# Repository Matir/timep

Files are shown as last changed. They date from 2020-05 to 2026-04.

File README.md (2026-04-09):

# Test Interface for Multiple Embedded Protocols

This is an Open Source Hardware board based around the FTDI FT2232H chip to
provide breakouts, buffering, and level conversion for a number of common
embedded hardware interfaces.  At present, this includes:

* SPI
* I2C
* JTAG
* SWD
* UART

It's intended to be easy to use and work with open source software, including
tools like OpenOCD and Flashrom.

## Archived

**This will not be maintained in any way. This eventually served as a prototype
and inspiration for [Tigard](https://github.com/tigard-tools/tigard), which was
productionized by [@securelyfitz](https://github.com/securelyfitz).**

## Usage

### Hardware Hookup

The hardware has dedicated headers for a variety of electrical interfaces.
Connect the desired interface to you target.  The pinout for SPI, I2C and UART
are printed on the board, SWD follows the ARM SWD standard, and JTAG is the ARM
20 pin JTAG interface.  (Electrically, however, it should work with most any
processor supporting JTAG.)

You may only use one of the SPI, I2C, SWD, and JTAG interfaces at any given
time.  The UART is handled by dedicated pins in the FT2232H, so can be used
simultaneously with one of the other interfaces.

There are 3 switches on the board.  The mode switch selects how the reference
power (for the interface) and the target are connected:

* **Isolated**: The interface is powered by the on-board voltage regulators, and the
  target must be powered by its own power supplies.  The power rails are not
  connected to one another.  You will almost always want to use this mode.
* **Bridged**: The interface is powered by the on-board voltage regulators which
  will also supply power to the target.  **The target must not be separately
  powered.**  This mode is useful for e.g., programming SPI/I2C flash out of
  circuit, or powering very small circuits -- maximum stable load is around 200mA.
* **Target**: The interface is partially powered from the target.
  (Specifically, the reference voltage for the level shifters.)  In theory, this
  can be used for cases where the target voltage is not 5v, 3.3v, or 1.8v.  The
  target voltage must still remain under 5V!

Note that the *ground* of your computer is connected to the *ground* of your
target when you connect with this.  In almost all cases, this is not a problem,
but if both are powered via the wall ("mains"), there is a risk of noise due to
ground loops, etc.

The voltage switch allows you to select the I/O voltage used in `Isolated` or
`Bridged` mode.  It does nothing (well, except change an LED) in `Target` mode.
5V is supplied directly from the USB input, and there are onboard regulators
for 3.3v and 1.8v.

The remaining switch selects between JTAG/SPI and I2C/SWD.  I2C and SWD use a
bidirectional data line, so require special handling.

### Software

I've tested the board with `OpenOCD` for JTAG/SWD use and `flashrom` for SPI/I2C
flash.  I'm planning to make a demo target board with a handful of interfaces on
it and provide that here in the future.

With `OpenOCD`, use the configuration file in `configs`.  You will also need a
target configuration.  Time permitting, I will post a tutorial on the use of
TIMEP and OpenOCD to debug targets.

With `flashrom`:

```
flashrom -p ft2232_spi:type=2232H,port=B,divisor=4
```

Use of `port=B` is critical, port `A` is wired to the UART, so will not work as
you intend.  :)

### Protections

Some efforts have been made to protect against mistakes that will destroy your
hardware, but there is still some risk in using this if connected improperly.

Included protection in current revision:

* Current limiting resistors on I/O lines.
* 5v+ tolerant I/O.
* Warnings in the README.  :)

Shorting power to ground may damage the target, the TIMEP interface, or the USB
port on your computer (if running in 5V mode).  This is unlikely, but be careful
with your connections.

Using the wrong voltage may damage components not rated for that voltage.  Any
voltage up to 5v is tolerated on the interface board I/O pins, but beyond that
may result in damage.

Additional protection that could be considered:

* Polyfuses on power/ground rails to computer.
* Clamping diodes on USB lines.
* Clamping diodes on I/O lines.

These have not been added because I have been trying to keep BOM cost down to
get these in the hands of as many hardware hackers as possible.

## License

Copyright 2020 Google, LLC

Maintainer: David Tomaschik <david@systemoverlord.com>

Please see [CONTRIBUTORS.md](CONTRIBUTORS.md) for credit to all contributors.

Licensed under the Apache License, Version 2.0 (the "License");
you may not use this file except in compliance with the License.
You may obtain a copy of the License at

    https://www.apache.org/licenses/LICENSE-2.0

Unless required by applicable law or agreed to in writing, software
distributed under the License is distributed on an "AS IS" BASIS,
WITHOUT WARRANTIES OR CONDITIONS OF ANY KIND, either express or implied.
See the License for the specific language governing permissions and
limitations under the License.

This is not an officially supported Google product.

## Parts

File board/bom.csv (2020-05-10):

Reference | Value | Footprint | Datasheet | Digikey | P/N | Comment
J1 | USB_B_Micro | Connector_USB:USB_Micro-B_Amphenol_10103594-0001LF_Horizontal | ~ | 609-4050-1-ND | 10103594
FB3 | 100 | Inductor_SMD:L_0805_2012Metric | ~ | 445-1567-1-ND | MPZ2012S101AT000
D2 | LED | LED_SMD:LED_0603_1608Metric | ~ | 732-4979-1-ND | 150060SS75000 | Substitution Okay
D3 | LED | LED_SMD:LED_0603_1608Metric | ~ | 732-4979-1-ND | 150060SS75000 | Substitution Okay
R8 | 1k | Resistor_SMD:R_0603_1608Metric | ~ | RMCF0603JT1K00CT-ND | RMCF0603JT1K00 | Substitution Okay
R9 | 1k | Resistor_SMD:R_0603_1608Metric | ~ | RMCF0603JT1K00CT-ND | RMCF0603JT1K00 | Substitution Okay
D4 | LED | LED_SMD:LED_0603_1608Metric | ~ | 732-4979-1-ND | 150060SS75000 | Substitution Okay
R10 | 1k | Resistor_SMD:R_0603_1608Metric | ~ | RMCF0603JT1K00CT-ND | RMCF0603JT1K00 | Substitution Okay
U5 | SN74LVC8T245 | Package_SO:SSOP-24_5.3x8.2mm_P0.65mm |  | 296-21065-1-ND | SN74LVC8T245DBR
U6 | SN74LVC8T245 | Package_SO:SSOP-24_5.3x8.2mm_P0.65mm |  | 296-21065-1-ND | SN74LVC8T245DBR
R11 | 10k | Resistor_SMD:R_0603_1608Metric | ~ | RMCF0603JT10K0CT-ND | RMCF0603JT10K0 | Substitution Okay
C18 | 0.1u | Capacitor_SMD:C_0603_1608Metric | ~ | 1276-1857-1-ND | CL10A104KA8NNNC | Substitution Okay
C19 | 0.1u | Capacitor_SMD:C_0603_1608Metric | ~ | 1276-1857-1-ND | CL10A104KA8NNNC | Substitution Okay
C20 | 0.1u | Capacitor_SMD:C_0603_1608Metric | ~ | 1276-1857-1-ND | CL10A104KA8NNNC | Substitution Okay
C21 | 0.1u | Capacitor_SMD:C_0603_1608Metric | ~ | 1276-1857-1-ND | CL10A104KA8NNNC | Substitution Okay
R12 | 10k | Resistor_SMD:R_0603_1608Metric | ~ | RMCF0603JT10K0CT-ND | RMCF0603JT10K0 | Substitution Okay
R13 | 10k | Resistor_SMD:R_0603_1608Metric | ~ | RMCF0603JT10K0CT-ND | RMCF0603JT10K0 | Substitution Okay
R14 | 1M | Resistor_SMD:R_0603_1608Metric | ~ | RMCF0603JT1M00CT-ND | RMCF0603JT1M00 | Substitution Okay
RN1 | 100k | Matir_Parts:EXB2HV | ~ | Y1104CT-ND | EXB-2HV104JV
RN2 | 100 | Matir_Parts:EXB2HV | ~ | Y1331CT-ND | EXB-2HV331JV
RN4 | 100k | Matir_Parts:EXB2HV | ~ | Y1104CT-ND | EXB-2HV104JV
RN3 | 100 | Matir_Parts:EXB2HV | ~ | Y1331CT-ND | EXB-2HV331JV
J6 | UART_Conn | Connector_PinHeader_2.54mm:PinHeader_1x09_P2.54mm_Vertical_SMD_Pin1Left | ~ | TSM-109-01-L-SV-P-ND | TSM-109-01-L-SV-P
J5 | JTAG_CONN | Connector_PinHeader_2.54mm:PinHeader_2x10_P2.54mm_Vertical_SMD | ~ | 609-6477-1-ND | 95278-801A20LF
J4 | SWD_CONN | Connector_PinHeader_1.27mm:PinHeader_2x05_P1.27mm_Vertical_SMD | ~ | 609-6118-1-ND | 20021121-00010C1L
J7 | SPI_CONN | Connector_PinHeader_2.54mm:PinHeader_2x04_P2.54mm_Vertical_SMD | ~ | 609-5811-1-ND | 95278-101A08LF
J8 | I2C_CONN | Connector_PinHeader_2.54mm:PinHeader_2x04_P2.54mm_Vertical_SMD | ~ | 609-5811-1-ND | 95278-101A08LF
R16 | 2.2k | Resistor_SMD:R_0603_1608Metric | ~ | RMCF0603JT2K20CT-ND | RMCF0603JT2K20 | Substitution Okay
R17 | 2.2k | Resistor_SMD:R_0603_1608Metric | ~ | RMCF0603JT2K20CT-ND | RMCF0603JT2K20 | Substitution Okay
D5 | RB751S40 | Diode_SMD:D_SOD-523 | ~ | RB751S40T1GOSCT-ND | RB751S40T1G
D6 | RB751S40 | Diode_SMD:D_SOD-523 | ~ | RB751S40T1GOSCT-ND | RB751S40T1G
H4 | MountingHole | MountingHole:MountingHole_3.2mm_M3 | ~
H2 | MountingHole | MountingHole:MountingHole_3.2mm_M3 | ~
H1 | MountingHole | MountingHole:MountingHole_3.2mm_M3 | ~
H3 | MountingHole | MountingHole:MountingHole_3.2mm_M3 | ~
SW3 | SW_DPDT_x2 | Matir_Parts:JS202011SCQN |  | 401-2002-1-ND | JS202011SCQN
R7 | 330 | Resistor_SMD:R_0603_1608Metric | ~ | RMCF0603JT330RCT-ND | RMCF0603JT330R | Substitution Okay
R15 | 1k | Resistor_SMD:R_0603_1608Metric | ~ | RMCF0603JT1K00CT-ND | RMCF0603JT1K00 | Substitution Okay
D1 | LED | LED_SMD:LED_0603_1608Metric | ~ | 732-4979-1-ND | 150060SS75000 | Substitution Okay
R22 | 10k | Resistor_SMD:R_0603_1608Metric | ~ | RMCF0603JT10K0CT-ND | RMCF0603JT10K0 | Substitution Okay
R21 | 10k | Resistor_SMD:R_0603_1608Metric | ~ | RMCF0603JT10K0CT-ND | RMCF0603JT10K0 | Substitution Okay
F1 | 500mA | Fuse:Fuse_1206_3216Metric | ~ | NANOSMDC050F/13.2-2CT-ND | NANOSMDC050F/13.2-2
U7 | USBLC6 | Package_TO_SOT_SMD:SOT-666 |  | 497-5026-1-ND | USBLC6-2P6
U1 | FT2232H-56 | Matir_Parts:FT2232H-56Q |  | 768-1276-ND | FT2232H-56Q-TRAY
C3 | 3.3u | Capacitor_SMD:C_0603_1608Metric | ~ | 1276-1892-1-ND | CL10A335KP8NNNC | Substitution Okay
R1 | 12k, 1% | Resistor_SMD:R_0603_1608Metric | ~ | RMCF0603FT12K0CT-ND | RMCF0603FT12K0
FB2 | 100 | Inductor_SMD:L_0805_2012Metric | ~ | 445-1567-1-ND | MPZ2012S101AT000
FB1 | 100 | Inductor_SMD:L_0805_2012Metric | ~ | 445-1567-1-ND | MPZ2012S101AT000
C4 | 2.2u | Capacitor_SMD:C_0603_1608Metric | ~ | 1276-1183-1-ND | CL10A225KQ8NNNC | Substitution Okay
C2 | 0.1u | Capacitor_SMD:C_0603_1608Metric | ~ | 1276-1857-1-ND | CL10A104KA8NNNC | Substitution Okay
C5 | 0.1u | Capacitor_SMD:C_0603_1608Metric | ~ | 1276-1857-1-ND | CL10A104KA8NNNC | Substitution Okay
C1 | 2.2u | Capacitor_SMD:C_0603_1608Metric | ~ | 1276-1183-1-ND | CL10A225KQ8NNNC | Substitution Okay
C8 | 0.1u | Capacitor_SMD:C_0603_1608Metric | ~ | 1276-1857-1-ND | CL10A104KA8NNNC | Substitution Okay
C9 | 0.1u | Capacitor_SMD:C_0603_1608Metric | ~ | 1276-1857-1-ND | CL10A104KA8NNNC | Substitution Okay
C10 | 0.1u | Capacitor_SMD:C_0603_1608Metric | ~ | 1276-1857-1-ND | CL10A104KA8NNNC | Substitution Okay
C11 | 0.1u | Capacitor_SMD:C_0603_1608Metric | ~ | 1276-1857-1-ND | CL10A104KA8NNNC | Substitution Okay
C12 | 0.1u | Capacitor_SMD:C_0603_1608Metric | ~ | 1276-1857-1-ND | CL10A104KA8NNNC | Substitution Okay
R2 | 10k | Resistor_SMD:R_0603_1608Metric | ~ | RMCF0603JT10K0CT-ND | RMCF0603JT10K0 | Substitution Okay
Y1 | 12.000MHz | Crystal:Crystal_SMD_HC49-SD | ~ | 535-15006-1-ND | ABLS-12.000MHZ-20-B-3-H-T
C7 | 27pf | Capacitor_SMD:C_0603_1608Metric | ~ | 311-1063-1-ND | CC0603JRNPO9BN270
C6 | 27pf | Capacitor_SMD:C_0603_1608Metric | ~ | 311-1063-1-ND | CC0603JRNPO9BN270
U2 | 93LC46B | Package_SO:SOIC-8_3.9x4.9mm_P1.27mm | http://ww1.microchip.com/downloads/en/DeviceDoc/20001749K.pdf | 93LC46BT-I/SNCT-ND | 93LC46BT-I/SN
C13 | 0.1u | Capacitor_SMD:C_0603_1608Metric | ~ | 1276-1857-1-ND | CL10A104KA8NNNC | Substitution Okay
R4 | 10k | Resistor_SMD:R_0603_1608Metric | ~ | RMCF0603JT10K0CT-ND | RMCF0603JT10K0 | Substitution Okay
R6 | 10k | Resistor_SMD:R_0603_1608Metric | ~ | RMCF0603JT10K0CT-ND | RMCF0603JT10K0 | Substitution Okay
R3 | 10k | Resistor_SMD:R_0603_1608Metric | ~ | RMCF0603JT10K0CT-ND | RMCF0603JT10K0 | Substitution Okay
R5 | 2.2k | Resistor_SMD:R_0603_1608Metric | ~ | RMCF0603JT2K20CT-ND | RMCF0603JT2K20 | Substitution Okay
C16 | 3.3u | Capacitor_SMD:C_0603_1608Metric | ~ | 1276-1892-1-ND | CL10A335KP8NNNC | Substitution Okay
C14 | 3.3u | Capacitor_SMD:C_0603_1608Metric | ~ | 1276-1892-1-ND | CL10A335KP8NNNC | Substitution Okay
C15 | 3.3u | Capacitor_SMD:C_0603_1608Metric | ~ | 1276-1892-1-ND | CL10A335KP8NNNC | Substitution Okay
C17 | 3.3u | Capacitor_SMD:C_0603_1608Metric | ~ | 1276-1892-1-ND | CL10A335KP8NNNC | Substitution Okay
U3 | AP2112K-3.3 | Package_TO_SOT_SMD:SOT-23-5 | https://www.diodes.com/assets/Datasheets/AP2112.pdf | AP2112K-3.3TRG1DICT-ND | AP2112K-3.3TRG1
U4 | AP2112K-1.8 | Package_TO_SOT_SMD:SOT-23-5 | https://www.diodes.com/assets/Datasheets/AP2112.pdf | AP2112K-1.8TRG1DICT-ND | AP2112K-1.8TRG1
SW1 | SW_DP3T | Matir_Parts:JS203011SCQN |  | CKN10849CT-ND | JS203011SCQN
R18 | 1k | Resistor_SMD:R_0603_1608Metric | ~ | RMCF0603JT1K00CT-ND | RMCF0603JT1K00 | Substitution Okay
R19 | 1k | Resistor_SMD:R_0603_1608Metric | ~ | RMCF0603JT1K00CT-ND | RMCF0603JT1K00 | Substitution Okay
R20 | 1k | Resistor_SMD:R_0603_1608Metric | ~ | RMCF0603JT1K00CT-ND | RMCF0603JT1K00 | Substitution Okay
D7 | 1v8 | LED_SMD:LED_0603_1608Metric | ~ | 732-4979-1-ND | 150060SS75000 | Substitution Okay
D8 | 3v3 | LED_SMD:LED_0603_1608Metric | ~ | 732-4979-1-ND | 150060SS75000 | Substitution Okay
D9 | 5v | LED_SMD:LED_0603_1608Metric | ~ | 732-4979-1-ND | 150060SS75000 | Substitution Okay
SW2 | SW_DP3T | Matir_Parts:JS203011SCQN |  | CKN10849CT-ND | JS203011SCQN
TP5V1 | TP5V | TestPoint:TestPoint_Pad_D2.0mm | ~
TP3v3 | TestPoint | TestPoint:TestPoint_Pad_D2.0mm | ~
TP1v8 | TestPoint | TestPoint:TestPoint_Pad_D2.0mm | ~
TPSET1 | TestPoint | TestPoint:TestPoint_Pad_D2.0mm | ~
TPTAR1 | TestPoint | TestPoint:TestPoint_Pad_D2.0mm | ~
TPVREF1 | TestPoint | TestPoint:TestPoint_Pad_D2.0mm | ~
TPGND1 | TestPoint | TestPoint:TestPoint_Pad_D2.0mm | ~
TPGND2 | TestPoint | Connector_PinHeader_2.54mm:PinHeader_1x01_P2.54mm_Vertical | ~ |  |  | No Populate

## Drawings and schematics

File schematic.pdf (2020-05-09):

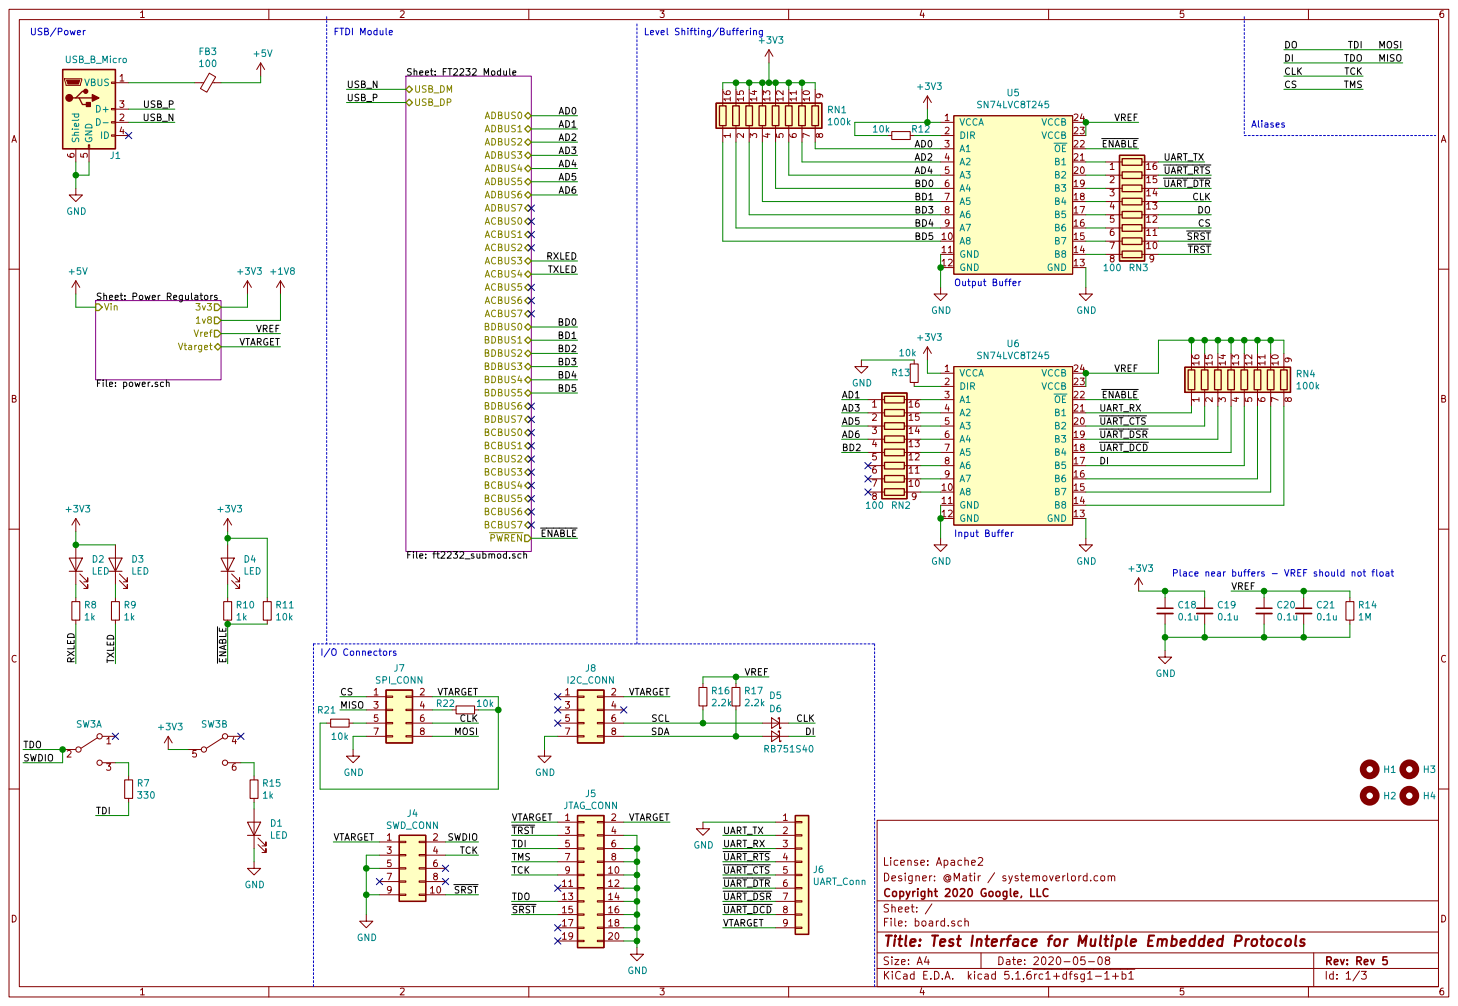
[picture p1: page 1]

Output Buffer USB/Power

License: Apache2
Designer: @Matir / systemoverlord.com
File: board.sch Sheet: / Copyright 2020 Google, LLC

Id: 1/3 Title: Test Interface for Multiple Embedded Protocols

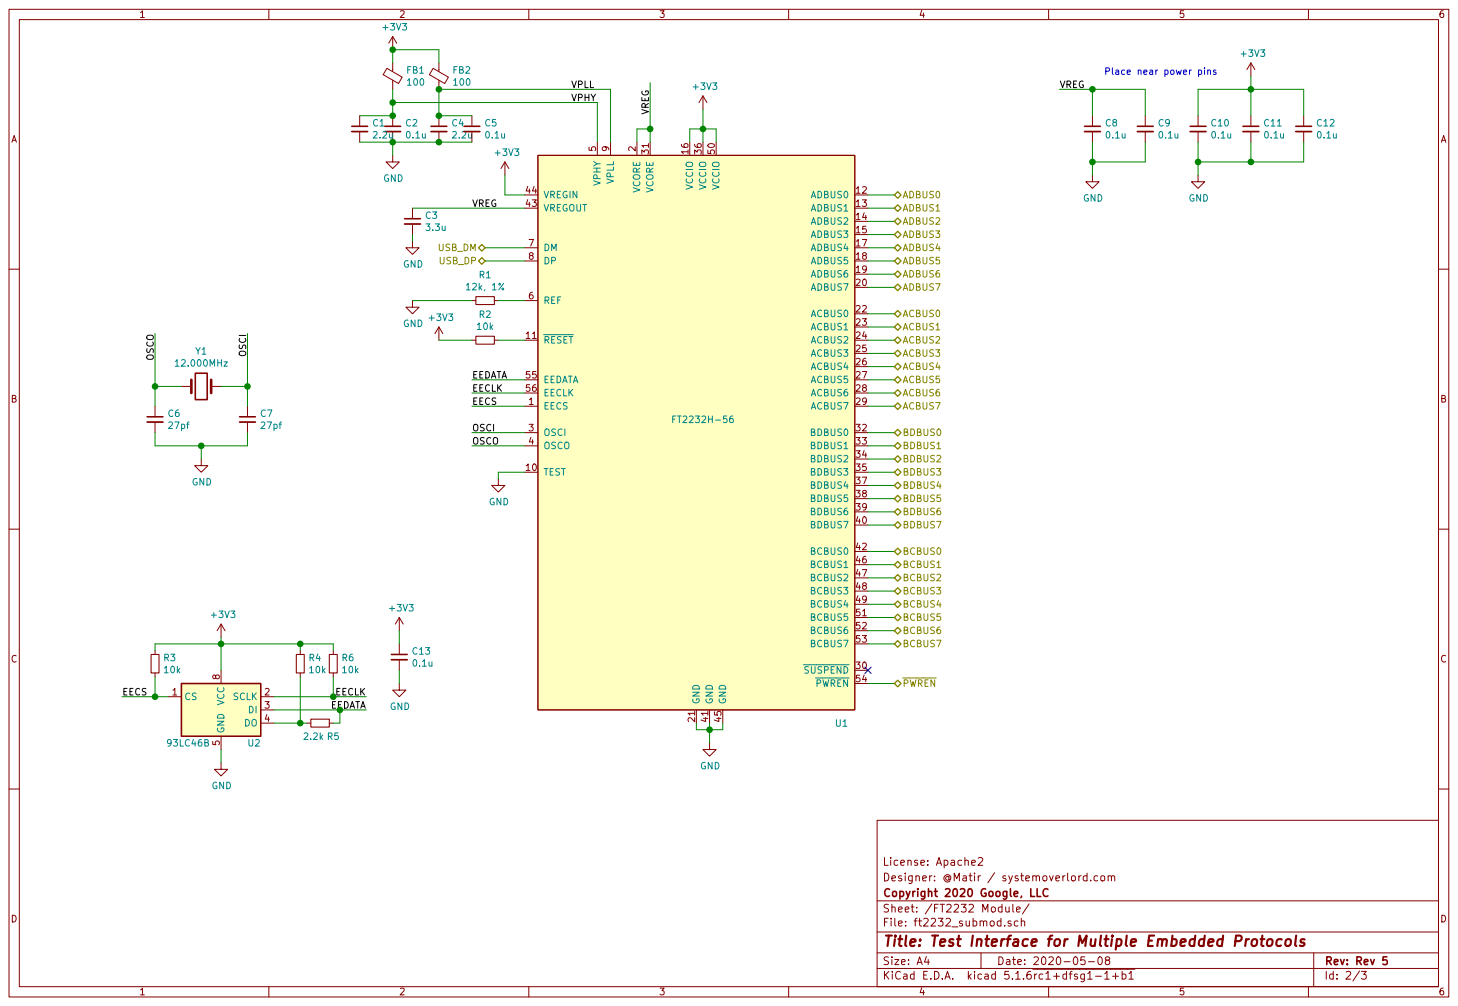
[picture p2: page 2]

Place near power pins

License: Apache2
Designer: @Matir / systemoverlord.com
File: ft2232_submod.sch Sheet: /FT2232 Module/ Copyright 2020 Google, LLC

Id: 2/3 Title: Test Interface for Multiple Embedded Protocols

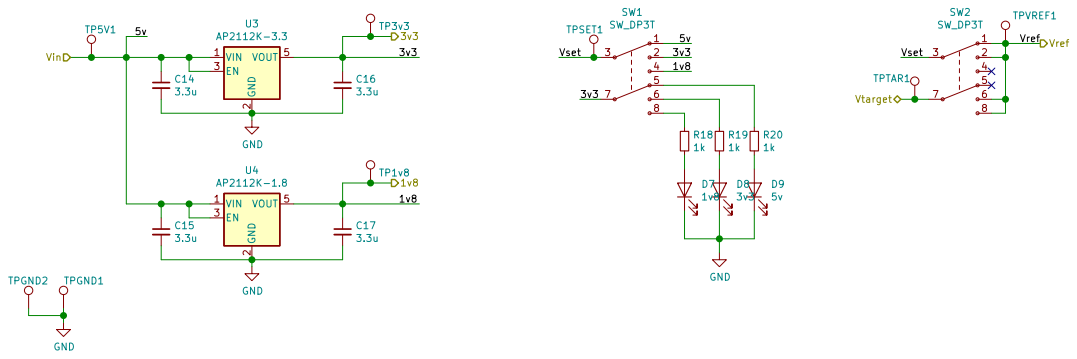
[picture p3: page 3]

2 EN 3 VOUT 5 U4 AP2112K-1.8 VIN 1 GND

Designer: @Matir / systemoverlord.com
Copyright 2020 Google, LLC
Sheet: /Power Regulators/
File: power.sch
Id: 3/3 Title: Test Interface for Multiple Embedded Protocols

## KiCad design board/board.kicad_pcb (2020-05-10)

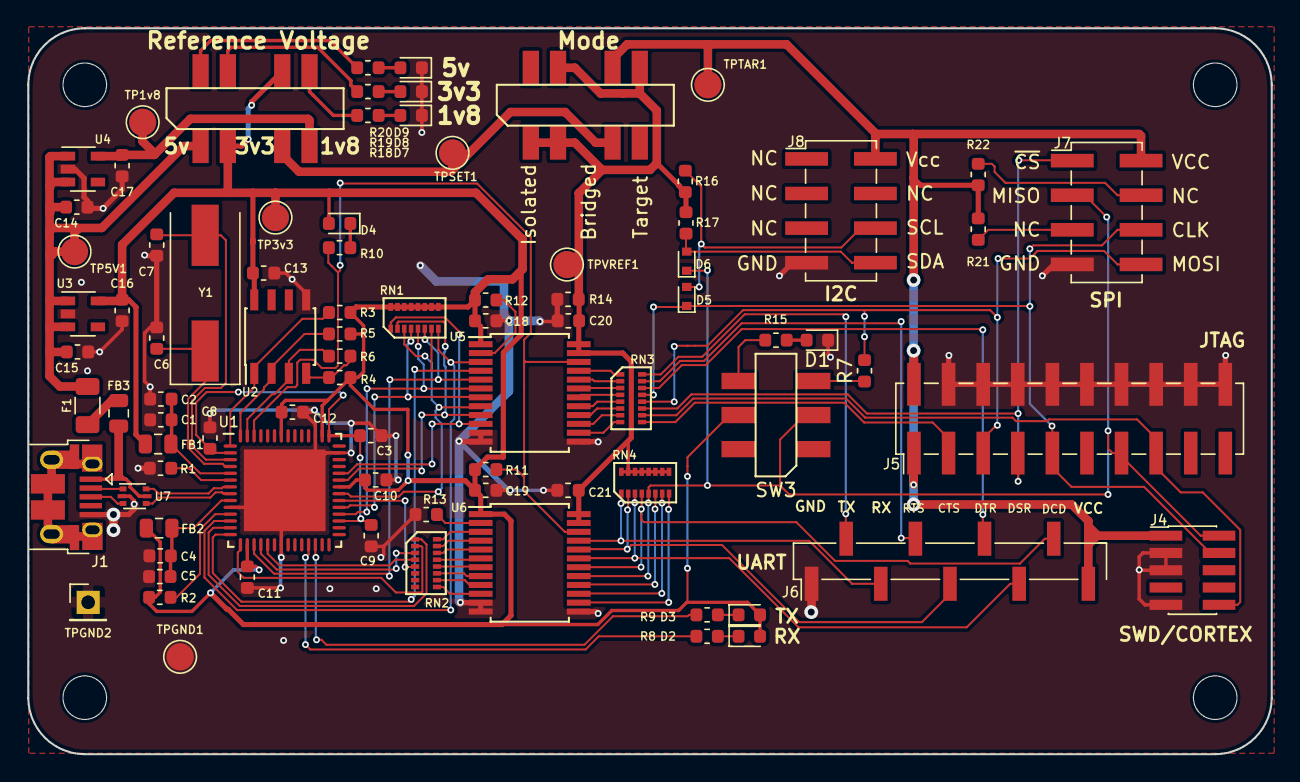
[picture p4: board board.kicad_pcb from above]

Board: 2 copper layers, 91.3 x 53.3 mm, 89 parts (0 on the bottom side), 90 nets.

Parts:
C1, C4: 2.2u; C_0603_1608Metric
C2, C5, C8, C9, C10, C11, C12, C13, C18, C19, C20, C21: 0.1u; C_0603_1608Metric
C3, C14, C15, C16, C17: 3.3u; C_0603_1608Metric
C6, C7: 27pf; C_0603_1608Metric
D1, D2, D3, D4: LED; LED_0603_1608Metric
D5, D6: RB751S40; D_SOD-523
D7: 1v8; LED_0603_1608Metric
D8: 3v3; LED_0603_1608Metric
D9: 5v; LED_0603_1608Metric
F1: 500mA; Fuse_1206_3216Metric
FB1, FB2, FB3: 100; L_0805_2012Metric
H1, H2, H3, H4: MountingHole; MountingHole_3.2mm_M3
J1: USB_B_Micro; USB_Micro-B_Amphenol_10103594-0001LF_Horizontal
J4: SWD_CONN; PinHeader_2x05_P1.27mm_Vertical_SMD
J5: JTAG_CONN; PinHeader_2x10_P2.54mm_Vertical_SMD
J6: UART_Conn; PinHeader_1x09_P2.54mm_Vertical_SMD_Pin1Left
J7: SPI_CONN; PinHeader_2x04_P2.54mm_Vertical_SMD
J8: I2C_CONN; PinHeader_2x04_P2.54mm_Vertical_SMD
R1: 12k, 1%; R_0603_1608Metric
R2, R3, R4, R6, R11, R12, R13, R21, R22: 10k; R_0603_1608Metric
R5, R16, R17: 2.2k; R_0603_1608Metric
R7: 330; R_0603_1608Metric
R8, R9, R10, R15, R18, R19, R20: 1k; R_0603_1608Metric
R14: 1M; R_0603_1608Metric
RN1, RN4: 100k; EXB2HV
RN2, RN3: 100; EXB2HV
SW1, SW2: SW_DP3T; JS203011SCQN
SW3: SW_DPDT_x2; JS202011SCQN
TP1v8, TP3v3: TestPoint; TestPoint_Pad_D2.0mm
TP5V1: TP5V; TestPoint_Pad_D2.0mm
TPGND1: TestPoint; TestPoint_Pad_D2.0mm
TPGND2: TestPoint; PinHeader_1x01_P2.54mm_Vertical
TPSET1: TestPoint; TestPoint_Pad_D2.0mm
TPTAR1: TestPoint; TestPoint_Pad_D2.0mm
TPVREF1: TestPoint; TestPoint_Pad_D2.0mm
U1: FT2232H-56; FT2232H-56Q
U2: 93LC46B; SOIC-8_3.9x4.9mm_P1.27mm
U3: AP2112K-3.3; SOT-23-5
U4: AP2112K-1.8; SOT-23-5
U5, U6: SN74LVC8T245; SSOP-24_5.3x8.2mm_P0.65mm
U7: USBLC6; SOT-666
Y1: 12.000MHz; Crystal_SMD_HC49-SD

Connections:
+1V8: C17.1, SW1.4, TP1v8.1, U4.5
+3V3: C10.1, C11.1, C12.1, C13.1, C16.1, C18.1, C19.1, D2.2, D3.2, D4.2, FB1.1, FB2.1, R2.2, R3.1, R4.1, R6.1, R11.1, R12.2, RN1.9, RN1.10, RN1.11, RN1.12, RN1.13, RN1.14, RN1.15, RN1.16, SW1.2, SW1.7, SW3.5, TP3v3.1, U1.16, U1.36, U1.44, U1.50, U2.8, U3.5, U5.1, U6.1
+5V: C14.1, C15.1, F1.1, SW1.1, TP5V1.1, U3.1, U3.3, U4.1, U4.3
/AD0: RN1.8, U1.12, U5.3
/AD1: RN2.1, U1.13
/AD2: RN1.7, U1.14, U5.4
/AD3: RN2.2, U1.15
/AD4: RN1.6, U1.17, U5.5
/AD5: RN2.3, U1.18
/AD6: RN2.4, U1.19
/BD0: RN1.5, U1.32, U5.6
/BD1: RN1.4, U1.33, U5.7
/BD2: RN2.5, U1.34
/BD3: RN1.3, U1.35, U5.8
/BD4: RN1.2, U1.37, U5.9
/BD5: RN1.1, U1.38, U5.10
/CLK: D5.1, J4.4, J5.9, J7.6, RN3.13
/CS: J5.7, J7.1, RN3.11
/DI: D6.1, J4.2, J5.13, J7.3, RN4.5, SW3.2, U6.17
/DO: J5.5, J7.8, R7.2, RN3.12
/FT2232 Module/EECLK: R6.2, U1.56, U2.2
/FT2232 Module/EECS: R3.2, U1.1, U2.1
/FT2232 Module/EEDATA: R5.1, U1.55, U2.3
/FT2232 Module/OSCI: C7.1, U1.3, Y1.2
/FT2232 Module/OSCO: C6.1, U1.4, Y1.1
/FT2232 Module/VPHY: C1.1, C2.1, FB1.2, U1.5
/FT2232 Module/VPLL: C4.1, C5.1, FB2.2, U1.9
/FT2232 Module/VREG: C3.1, C8.1, C9.1, U1.2, U1.31, U1.43
/Power Regulators/Vset: SW1.3, SW2.3, TPSET1.1
/RXLED: R8.2, U1.25
/SCL: D5.2, J8.6, R16.2
/SDA: D6.2, J8.8, R17.2
/TXLED: R9.2, U1.26
/UART_RX: J6.3, RN4.1, U6.21
/UART_TX: J6.2, RN3.16
/USB_N: U1.7, U7.6
/USB_P: U1.8, U7.4
/VBUS: FB3.2, J1.1, U7.5
/VREF: C20.1, C21.1, R14.1, R16.1, R17.1, RN4.9, RN4.10, RN4.11, RN4.12, RN4.13, RN4.14, RN4.15, RN4.16, SW2.1, SW2.2, SW2.6, SW2.8, TPVREF1.1, U5.23, U5.24, U6.23, U6.24
/VTARGET: J4.1, J5.1, J5.2, J6.9, J7.2, J8.2, R21.2, R22.1, SW2.7, TPTAR1.1
/~ENABLE: R10.2, R11.2, U1.54, U5.22, U6.22
/~SRST: J4.10, J5.15, RN3.10
/~TRST: J5.3, RN3.9
/~UART_CTS: J6.5, RN4.2, U6.20
/~UART_DCD: J6.8, RN4.4, U6.18
/~UART_DSR: J6.7, RN4.3, U6.19
/~UART_DTR: J6.6, RN3.14
/~UART_RTS: J6.4, RN3.15
GND: C1.2, C2.2, C3.2, C4.2, C5.2, C6.2, C7.2, C8.2, C9.2, C10.2, C11.2, C12.2, C13.2, C14.2, C15.2, C16.2, C17.2, C18.2, C19.2, C20.2, C21.2, D1.1, D7.1, D8.1, D9.1, J1.5, J4.3, J4.5, J4.9, J5.4, J5.6, J5.8, J5.10, J5.12, J5.14, J5.16, J5.18, J5.20, J6.1, J7.7, J8.7, R1.2, R13.2, R14.2, TPGND1.1, TPGND2.1, U1.10, U1.21, U1.41, U1.45, U2.5, U3.2, U4.2, U5.11, U5.12, U5.13, U6.11, U6.12, U6.13, U7.2
unnamed: D1.2, R15.2
unnamed: D2.1, R8.1
unnamed: D3.1, R9.1
unnamed: D4.1, R10.1
unnamed: D7.2, R18.2
unnamed: D8.2, R19.2
unnamed: D9.2, R20.2
unnamed: F1.2, FB3.1
unnamed: J1.2, U7.1
unnamed: J1.3, U7.3
unnamed: J7.4, R22.2
unnamed: J7.5, R21.1
unnamed: R1.1, U1.6
unnamed: R2.1, U1.11
unnamed: R4.2, R5.2, U2.4
unnamed: R7.1, SW3.3
unnamed: R12.1, U5.2
unnamed: R13.1, U6.2
unnamed: R15.1, SW3.6
unnamed: R18.1, SW1.8
unnamed: R19.1, SW1.6
unnamed: R20.1, SW1.5
unnamed: RN2.9, U6.10
unnamed: RN2.10, U6.9
unnamed: RN2.11, U6.8
unnamed: RN2.12, U6.7
unnamed: RN2.13, U6.6
unnamed: RN2.14, U6.5
unnamed: RN2.15, U6.4
unnamed: RN2.16, U6.3
unnamed: RN3.1, U5.21
unnamed: RN3.2, U5.20
unnamed: RN3.3, U5.19
unnamed: RN3.4, U5.18
unnamed: RN3.5, U5.17
unnamed: RN3.6, U5.16
unnamed: RN3.7, U5.15
unnamed: RN3.8, U5.14
unnamed: RN4.6, U6.16
unnamed: RN4.7, U6.15
unnamed: RN4.8, U6.14

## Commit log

2020-04-08 Prepare TIMEP for release.
    [board-B_Cu.gbr, board-B_Mask.gbr, board-B_Paste.gbr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]
2020-05-09 Update for release.
    [board-B_Cu.gbr, board-B_Mask.gbr, board-B_Paste.gbr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]
2020-05-10 Add protection (ESD, PTC fusing) to MicroUSB port
    Schematic changes:
    * No connect SHIELD on the MicroUSB port. Since we have no SHIELD GND, I
    think it's best to leave the shield unconnected rather than connect it
    to our digital GND and potentially introduce noise. This seems to be
    backed up by the FTDI USB Design Guidelines
    (https://www.ftdichip.com/Support/Documents/AppNotes/AN_146_USB_Hardware_Design_Guidelines_for_FTDI_ICs.pdf)
    * Inline a USBLC-6 for transient voltage supression on our USB data lines
    and VBUS
    * Add a 500mA hold current PTC after the ferrite bead on VBUS. This PTC
    should help protect the host computer if the board short circuits
    Layout changes:
    * Moves the passives (C2,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
    [board.kicad_pcb, board.sch, bom.csv]

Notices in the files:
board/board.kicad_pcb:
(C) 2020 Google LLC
